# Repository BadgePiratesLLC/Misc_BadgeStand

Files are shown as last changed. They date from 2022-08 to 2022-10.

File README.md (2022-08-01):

# Misc_BadgeStand
Powered Stand for holding and running your badge(s)

Build Instructions:
<pic of Built Stand>

Your badge stand shipped with 2 stand bases, one is a blank PCB and the other is populated with Electronics that drop 5v from a micro USB down to 3.3v at the 2 pin locations. Of course one is 3.3v and the other is GND (see Pic below). 

<pic of pins with Labels> (Still needs Added)

Additionally you have 4 stand offs of 2 different sizes, 2 screws and 2 nuts. Use these to connect your 2 Base pieces to each other, using the sizes to adjust the space between the bases.

<Pic or Video of Connecting the Standoffs to Bases>(Still needs Added)

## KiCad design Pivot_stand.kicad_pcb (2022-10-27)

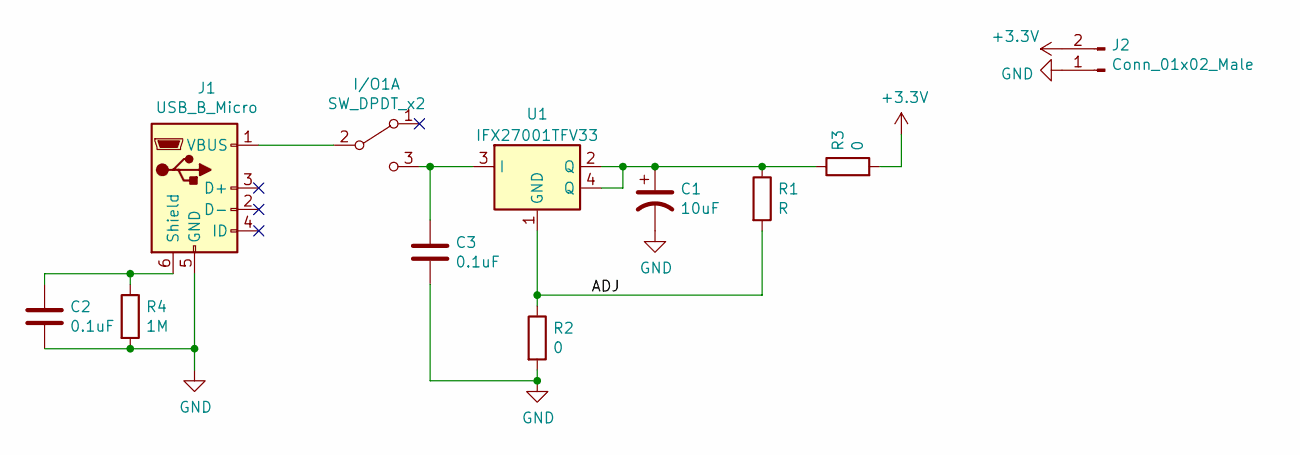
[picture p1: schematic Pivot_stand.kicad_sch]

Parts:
C1: 10uF; C_0805_2012Metric
C2, C3: 0.1uF; C_0805_2012Metric
I/O1: SW_DPDT_x2; SW_SPDT_PCM12
J1: USB_B_Micro; USB_Micro-B_Wuerth_629105150521
J2: Conn_01x02_Male; PinHeader_1x02_P2.00mm_Vertical
R1: R; R_1206_3216Metric
R2, R3: 0; R_1206_3216Metric
R4: 1M; R_1206_3216Metric
U1: IFX27001TFV33; SOT-223

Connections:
+3V3: J2.2, R3.2
/ADJ: R1.2, R2.1, U1.1 (GND)
GND: C1.2, C2.2, C3.2, J1.5 (GND), J2.1, R2.2, R4.2
unnamed: C1.1, R1.1, R3.1, U1.2 (Q), U1.4 (Q)
unnamed: C2.1, J1.6 (Shield), R4.1
unnamed: C3.1, I/O1.3 (C), U1.3 (I)
unnamed: I/O1.2 (B), J1.1 (VBUS)

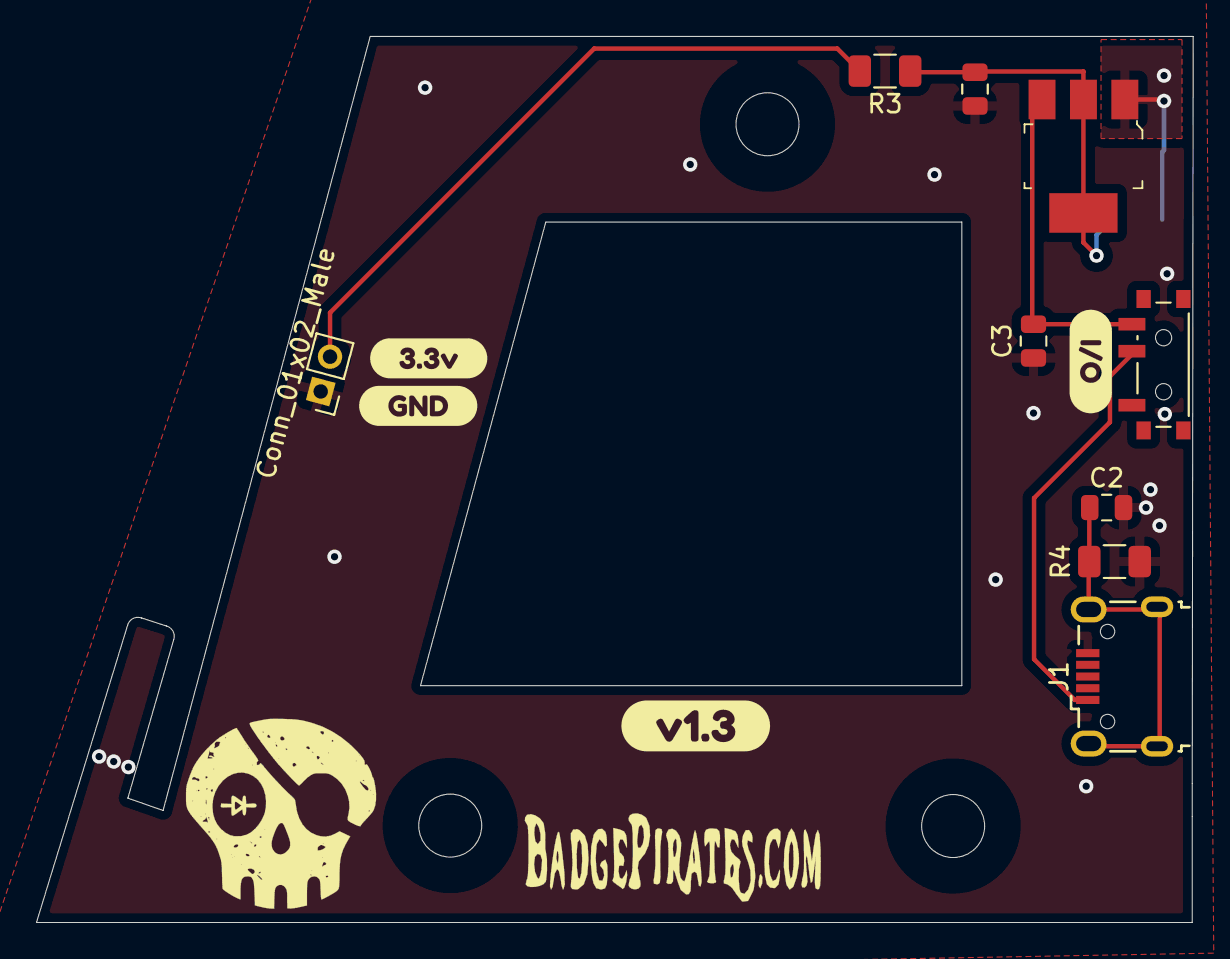
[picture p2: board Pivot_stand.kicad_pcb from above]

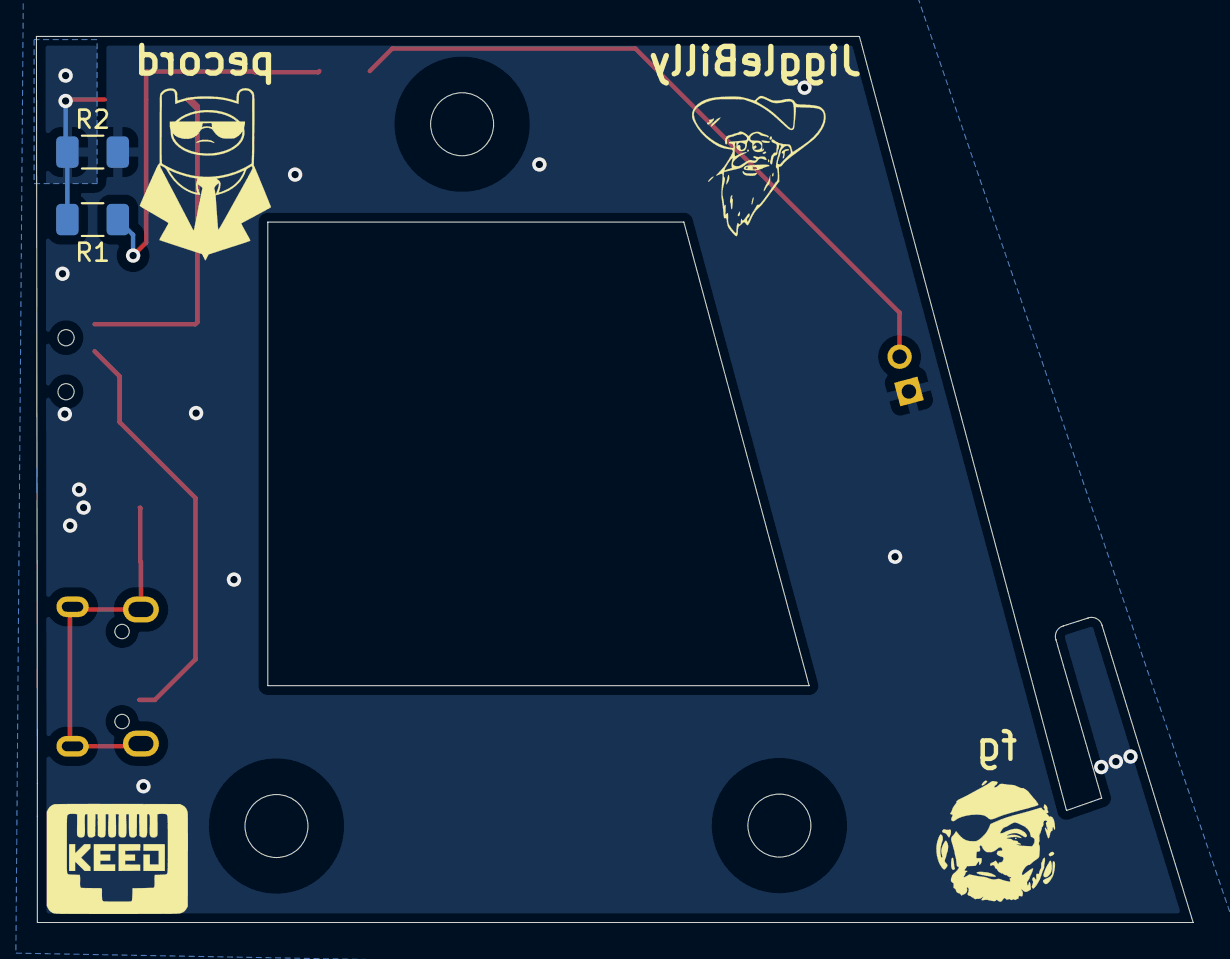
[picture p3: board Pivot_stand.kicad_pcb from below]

Board: 2 copper layers, 64.3 x 49.2 mm, 15 parts (2 on the bottom side), 7 nets.

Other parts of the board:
kibuzzard-629C349E: G***; kibuzzard-629C349E
kibuzzard-629C2456: G***; kibuzzard-629C2456
kibuzzard-629C2481: G***; kibuzzard-629C2481
kibuzzard-629C3492: G***; kibuzzard-629C3492

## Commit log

2022-08-01 Create CAD
2022-10-16 Schematic cleanup
    Moved text in schematic to make it more readable
    [Pivot_stand.sch]
2022-10-16 Improvements
    Added resistor from pin 1 of regulator to ground to allow for Adj regulator to be used. Defaulted to 0 ohm.
    Added 0 ohm resistor to voltage output. This allows a resistance to be added in to protect SAOs with no current limiting resistor on LEDs.
    Tied USB shield to ground using 1M resistor and 0.1uF cap.
    [Pivot_stand.sch]
2022-10-16 Updated format to KiCad 6
    Updated format to KiCad 6
    [Pivot_stand.kicad_sch]
2022-10-16 Changed Fill
    Changed the fill type from hatched to solid to improve signal integrity
    [Pivot_stand.kicad_pcb]
2022-10-16 Changed the regulator symbol
    Changed the regulator symbol to include a 4th pin for the output tab.
    [Pivot_stand.kicad_sch]
2022-10-16 Updated U1 footprint
    Updated the U1 footprint
    [Pivot_stand.kicad_sch]
2022-10-16 Changed footprint library
    Changed footprint library to use the BadgePirtate library
    [Pivot_stand.kicad_sch]
2022-10-16 Change SW1 footprint
    Changed SW1 footprint to use the BP lib
    [Pivot_stand.kicad_sch]
2022-10-16 Fixed ref des
    Fixed I/O ref des
    [Pivot_stand.kicad_sch]
2022-10-16 Layout updates
    Added new parts to PCB to match schematic changes.
    [Pivot_stand.kicad_pcb, Pivot_stand.kicad_sch]
